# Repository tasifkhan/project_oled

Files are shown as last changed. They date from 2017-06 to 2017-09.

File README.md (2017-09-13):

## project_oled
- Display driver for 8x8 OLED array. Common anode setup for 64 devices, controlled by Darlington arrays and an Arduino Mega.
- Arduino code for displaying letters and numbers for the array, also a seven segment display.

### notes
- 2017_08_27 second round of cleaning. If you plan to use this design, DO NOT connect pin 10 of the Darlington arrays, leave that pin floating.
- 2017_07_18 cleanup. Hardware works with pin 10 NC. Uploading arduino firmware for seven segment and 4x4 displays.
- 2017_07_04 remove COM to GND connection in v1 (pin 10 NC). Other than that v1 works.

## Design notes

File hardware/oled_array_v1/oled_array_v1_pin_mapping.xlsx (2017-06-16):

 |  |  |  |  |  |  |  |  | x1 | x2
 |  |  |  |  |  |  |  |  | A7 | 13
 | 1 | 2 | 3 | 4 | 5 | 6 | 7 | 8 | A6 | 12
1 | A4 | A5 | A6 | A7 | 13 | 12 | 11 | 10 | A5 | 11
2 | A0 | A1 | A2 | A3 | 9 | 8 | 7 | 6 | A4 | 10
3 | A11 | A10 | A9 | A8 | 5 | 4 | 3 | 2 | A3 | 9
4 | 50 | 51 | 52 | 53 | 14 | 15 | 16 | 17 | A2 | 8
5 | 44 | 45 | 42 | 43 | 18 | 19 | 20 | 21 | A1 | 7
6 | 48 | 49 | 46 | 47 | 22 | 23 | 24 | 25 | A0 | 6
7 | 38 | 39 | 40 | 41 | 26 | 27 | 28 | 29 | A8 | 5
8 | 34 | 35 | 36 | 37 | 30 | 31 | 32 | 33 | A9 | 4
 |  |  |  |  |  |  |  |  | A10 | 3
 |  |  |  |  |  |  |  |  | A11 | 2
 |  |  |  |  |  |  |  |  | 53 | 14
 |  |  |  |  |  |  |  |  | 52 | 15
 |  |  |  |  |  |  |  |  | 51 | 16
 |  |  |  |  |  |  |  |  | 50 | 17
 |  |  |  |  |  |  |  |  | 43 | 18
 |  |  |  |  |  |  |  |  | 42 | 19
 |  |  |  |  |  |  |  |  | 45 | 20
 |  |  |  |  |  |  |  |  | 44 | 21
 |  |  |  |  |  |  |  |  | 47 | 22
 |  |  |  |  |  |  |  |  | 46 | 23
 |  |  |  |  |  |  |  |  | 49 | 24
 |  |  |  |  |  |  |  |  | 48 | 25
 |  |  |  |  |  |  |  |  | 41 | 26
 |  |  |  |  |  |  |  |  | 40 | 27
 |  |  |  |  |  |  |  |  | 39 | 28
 |  |  |  |  |  |  |  |  | 38 | 29
 |  |  |  |  |  |  |  |  | 37 | 30
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

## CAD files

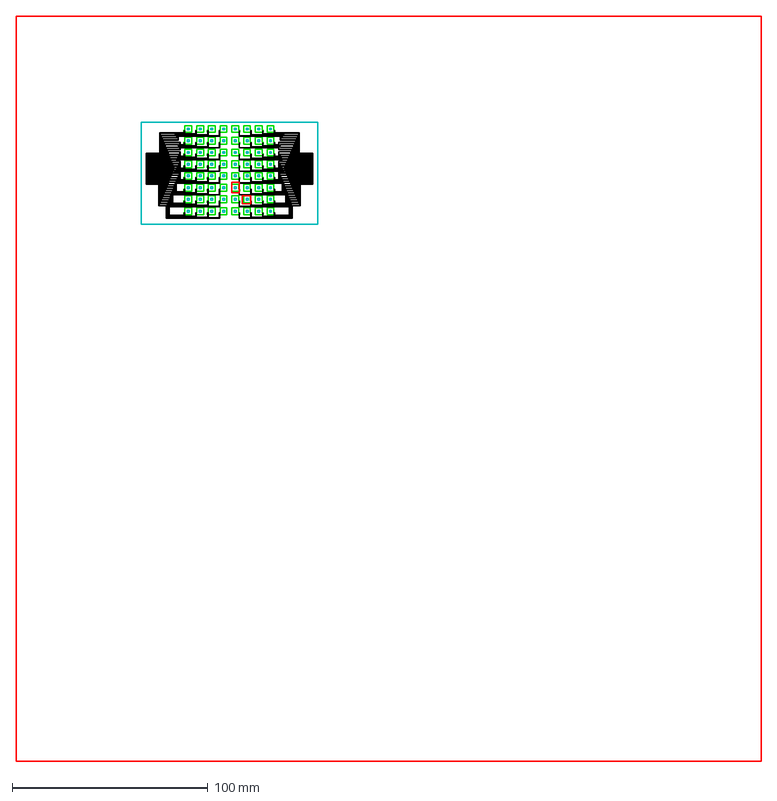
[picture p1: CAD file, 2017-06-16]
hardware/array_dxf/oled_array.dxf
381.0 x 381.0 mm

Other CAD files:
hardware/array_dxf/Master_OPD_array.dwg
hardware/array_dxf/oled_array.dwg

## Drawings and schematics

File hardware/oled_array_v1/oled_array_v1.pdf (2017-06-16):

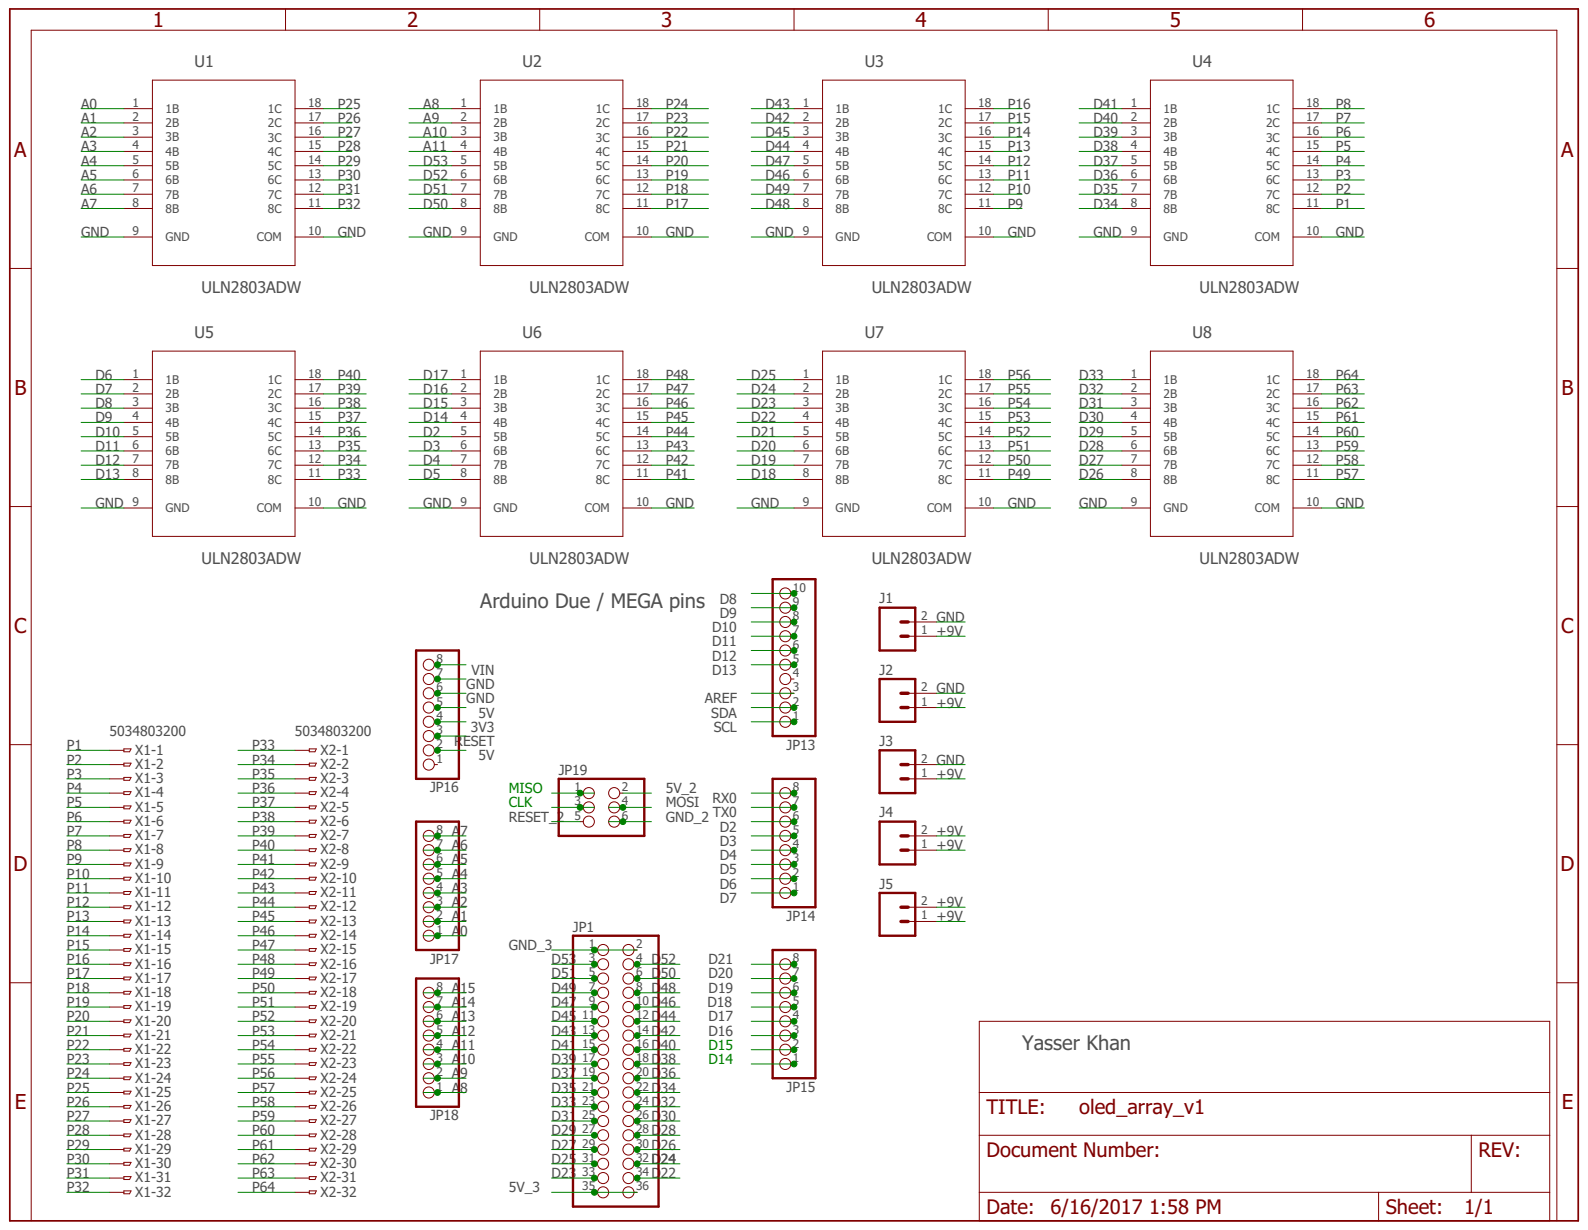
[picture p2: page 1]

Arduino Due / MEGA pins

Document Number: | REV:

Date: 6/16/2017 1:58 PM | Sheet: 1/1

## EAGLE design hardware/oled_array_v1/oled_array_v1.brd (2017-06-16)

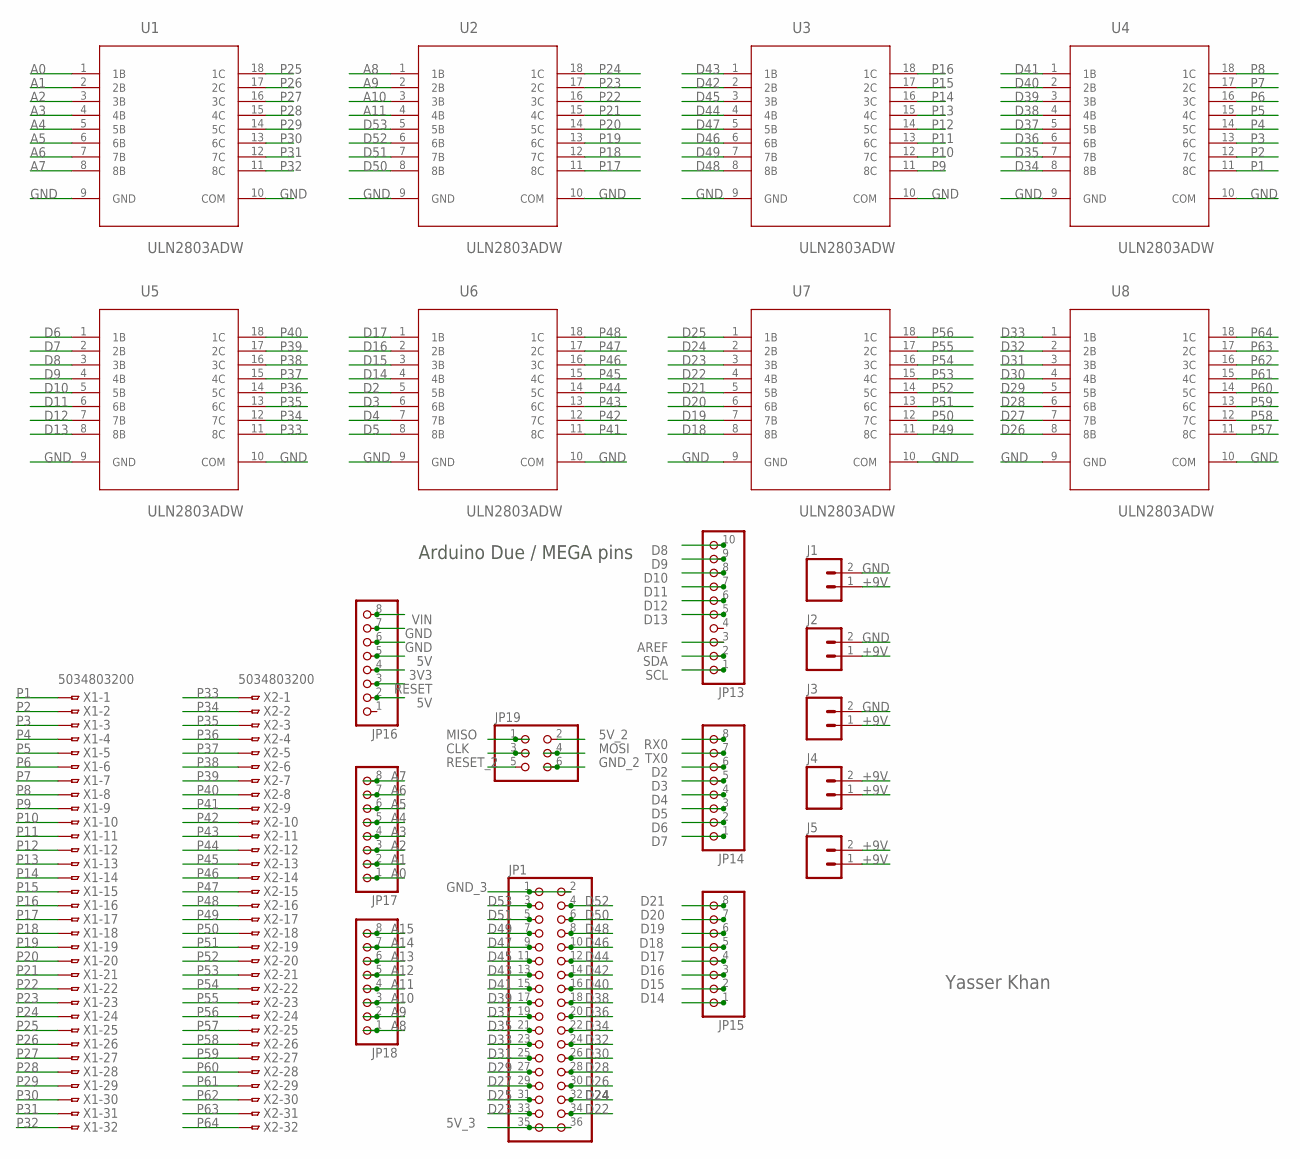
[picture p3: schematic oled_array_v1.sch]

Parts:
J1, J2, J3, J4, J5: M02PTH; 1X02
JP1: PINHD-2X18; 2X18
JP13: PINHD-1X10; 1X10
JP14, JP15, JP16, JP17, JP18: PINHD-1X8; 1X08
JP19: PINHD-2X3; 2X03
U1, U2, U3, U4, U5, U6, U7, U8: ULN2803ADW; SOIC127P1030X265-18N
X1, X2: 5034803200

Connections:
3V3: JP16.4
5V: JP16.2, JP16.5
5V_2: JP19.2
5V_3: JP1.35, JP1.36
+9V: J1.1, J2.1, J3.1, J4.1, J4.2, J5.1, J5.2
A0: JP17.1, U1.1 (1B)
A1: JP17.2, U1.2 (2B)
A2: JP17.3, U1.3 (3B)
A3: JP17.4, U1.4 (4B)
A4: JP17.5, U1.5 (5B)
A5: JP17.6, U1.6 (6B)
A6: JP17.7, U1.7 (7B)
A7: JP17.8, U1.8 (8B)
A8: JP18.1, U2.1 (1B)
A9: JP18.2, U2.2 (2B)
A10: JP18.3, U2.3 (3B)
A11: JP18.4, U2.4 (4B)
A12: JP18.5
A13: JP18.6
A14: JP18.7
A15: JP18.8
AREF: JP13.3
CLK: JP19.3
D2: JP14.6, U6.5 (5B)
D3: JP14.5, U6.6 (6B)
D4: JP14.4, U6.7 (7B)
D5: JP14.3, U6.8 (8B)
D6: JP14.2, U5.1 (1B)
D7: JP14.1, U5.2 (2B)
D8: JP13.10, U5.3 (3B)
D9: JP13.9, U5.4 (4B)
D10: JP13.8, U5.5 (5B)
D11: JP13.7, U5.6 (6B)
D12: JP13.6, U5.7 (7B)
D13: JP13.5, U5.8 (8B)
D14: JP15.1, U6.4 (4B)
D15: JP15.2, U6.3 (3B)
D16: JP15.3, U6.2 (2B)
D17: JP15.4, U6.1 (1B)
D18: JP15.5, U7.8 (8B)
D19: JP15.6, U7.7 (7B)
D20: JP15.7, U7.6 (6B)
D21: JP15.8, U7.5 (5B)
D22: JP1.34, U7.4 (4B)
D23: JP1.33, U7.3 (3B)
D24: JP1.32, U7.2 (2B)
D25: JP1.31, U7.1 (1B)
D26: JP1.30, U8.8 (8B)
D27: JP1.29, U8.7 (7B)
D28: JP1.28, U8.6 (6B)
D29: JP1.27, U8.5 (5B)
D30: JP1.26, U8.4 (4B)
D31: JP1.25, U8.3 (3B)
D32: JP1.24, U8.2 (2B)
D33: JP1.23, U8.1 (1B)
D34: JP1.22, U4.8 (8B)
D35: JP1.21, U4.7 (7B)
D36: JP1.20, U4.6 (6B)
D37: JP1.19, U4.5 (5B)
D38: JP1.18, U4.4 (4B)
D39: JP1.17, U4.3 (3B)
D40: JP1.16, U4.2 (2B)
D41: JP1.15, U4.1 (1B)
D42: JP1.14, U3.2 (2B)
D43: JP1.13, U3.1 (1B)
D44: JP1.12, U3.4 (4B)
D45: JP1.11, U3.3 (3B)
D46: JP1.10, U3.6 (6B)
D47: JP1.9, U3.5 (5B)
D48: JP1.8, U3.8 (8B)
D49: JP1.7, U3.7 (7B)
D50: JP1.6, U2.8 (8B)
D51: JP1.5, U2.7 (7B)
D52: JP1.4, U2.6 (6B)
D53: JP1.3, U2.5 (5B)
GND: J1.2, J2.2, J3.2, JP16.6, JP16.7, U1.9 (GND), U1.10 (COM), U2.9 (GND), U2.10 (COM), U3.9 (GND), U3.10 (COM), U4.9 (GND), U4.10 (COM), U5.9 (GND), U5.10 (COM), U6.9 (GND), U6.10 (COM), U7.9 (GND), U7.10 (COM), U8.9 (GND), U8.10 (COM)
GND_2: JP19.6
GND_3: JP1.1, JP1.2
MISO: JP19.1
MOSI: JP19.4
P1: U4.11 (8C), X1.1
P2: U4.12 (7C), X1.2
P3: U4.13 (6C), X1.3
P4: U4.14 (5C), X1.4
P5: U4.15 (4C), X1.5
P6: U4.16 (3C), X1.6
P7: U4.17 (2C), X1.7
P8: U4.18 (1C), X1.8
P9: U3.11 (8C), X1.9
P10: U3.12 (7C), X1.10
P11: U3.13 (6C), X1.11
P12: U3.14 (5C), X1.12
P13: U3.15 (4C), X1.13
P14: U3.16 (3C), X1.14
P15: U3.17 (2C), X1.15
P16: U3.18 (1C), X1.16
P17: U2.11 (8C), X1.17
P18: U2.12 (7C), X1.18
P19: U2.13 (6C), X1.19
P20: U2.14 (5C), X1.20
P21: U2.15 (4C), X1.21
P22: U2.16 (3C), X1.22
P23: U2.17 (2C), X1.23
P24: U2.18 (1C), X1.24
P25: U1.18 (1C), X1.25
P26: U1.17 (2C), X1.26
P27: U1.16 (3C), X1.27
P28: U1.15 (4C), X1.28
P29: U1.14 (5C), X1.29
P30: U1.13 (6C), X1.30
P31: U1.12 (7C), X1.31
P32: U1.11 (8C), X1.32
P33: U5.11 (8C), X2.1
P34: U5.12 (7C), X2.2
P35: U5.13 (6C), X2.3
P36: U5.14 (5C), X2.4
P37: U5.15 (4C), X2.5
P38: U5.16 (3C), X2.6
P39: U5.17 (2C), X2.7
P40: U5.18 (1C), X2.8
P41: U6.11 (8C), X2.9
P42: U6.12 (7C), X2.10
P43: U6.13 (6C), X2.11
P44: U6.14 (5C), X2.12
P45: U6.15 (4C), X2.13
P46: U6.16 (3C), X2.14
P47: U6.17 (2C), X2.15
P48: U6.18 (1C), X2.16
P49: U7.11 (8C), X2.17
P50: U7.12 (7C), X2.18
P51: U7.13 (6C), X2.19
P52: U7.14 (5C), X2.20
P53: U7.15 (4C), X2.21
P54: U7.16 (3C), X2.22
P55: U7.17 (2C), X2.23
P56: U7.18 (1C), X2.24
P57: U8.11 (8C), X2.25
P58: U8.12 (7C), X2.26
P59: U8.13 (6C), X2.27
P60: U8.14 (5C), X2.28
P61: U8.15 (4C), X2.29
P62: U8.16 (3C), X2.30
P63: U8.17 (2C), X2.31
P64: U8.18 (1C), X2.32
RESET: JP16.3
RESET_2: JP19.5
RX0: JP14.8
SCL: JP13.1
SDA: JP13.2
TX0: JP14.7
VIN: JP16.8

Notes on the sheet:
Arduino Due / MEGA pins
Yasser Khan

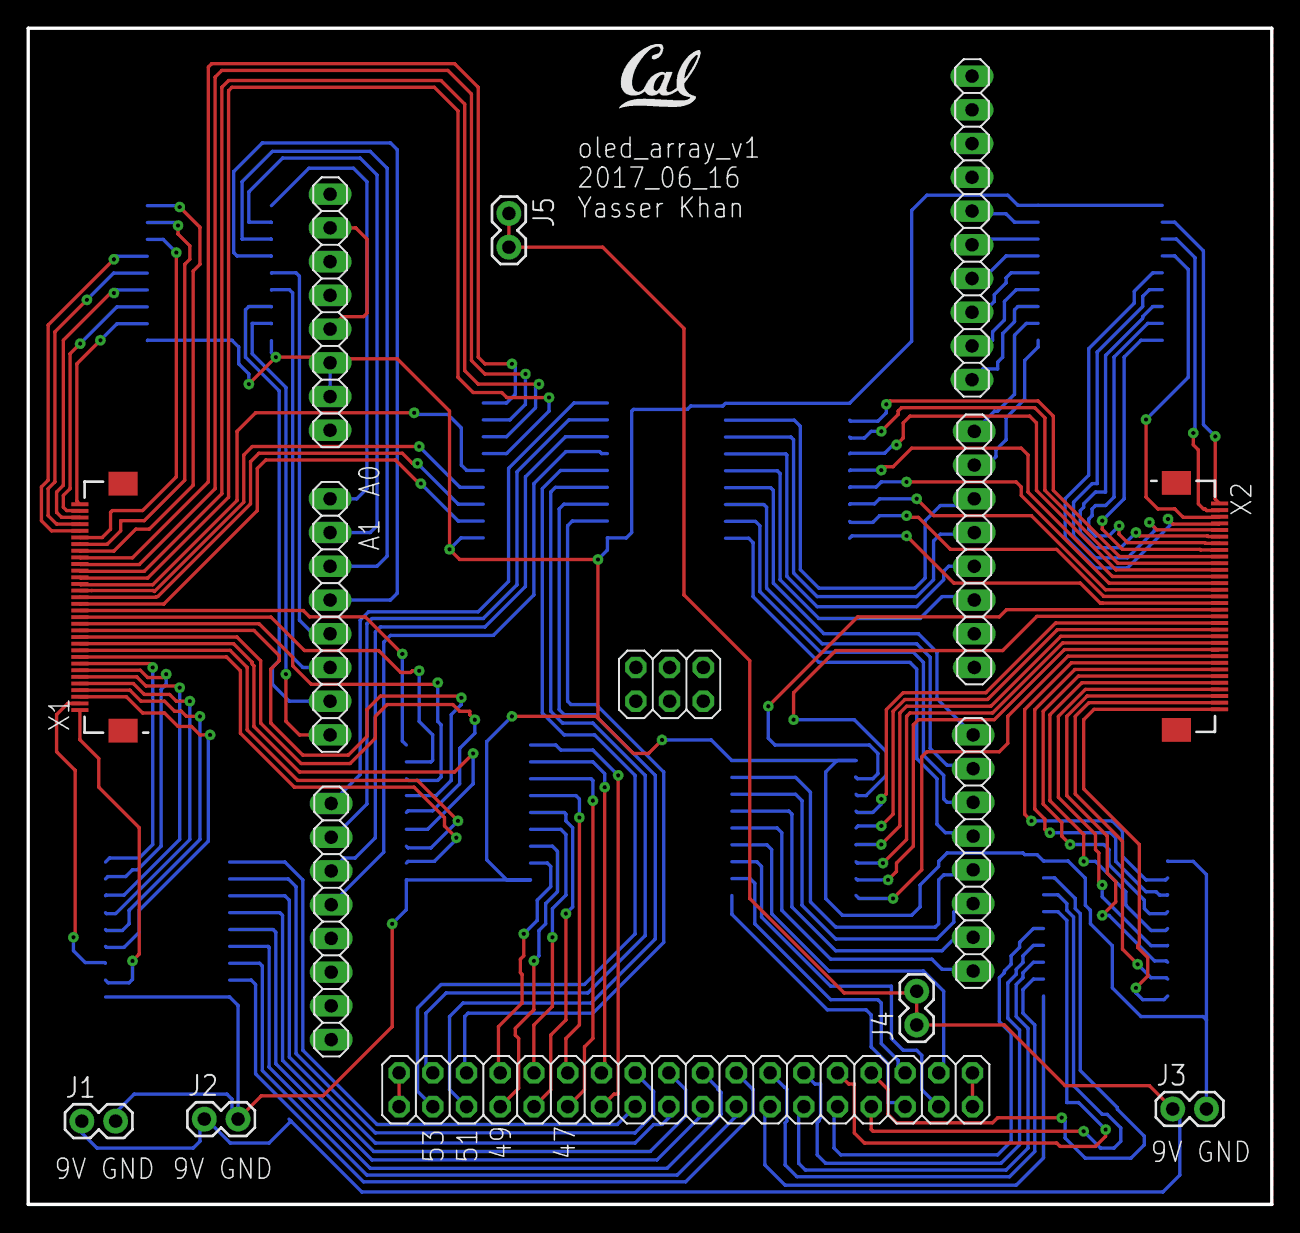
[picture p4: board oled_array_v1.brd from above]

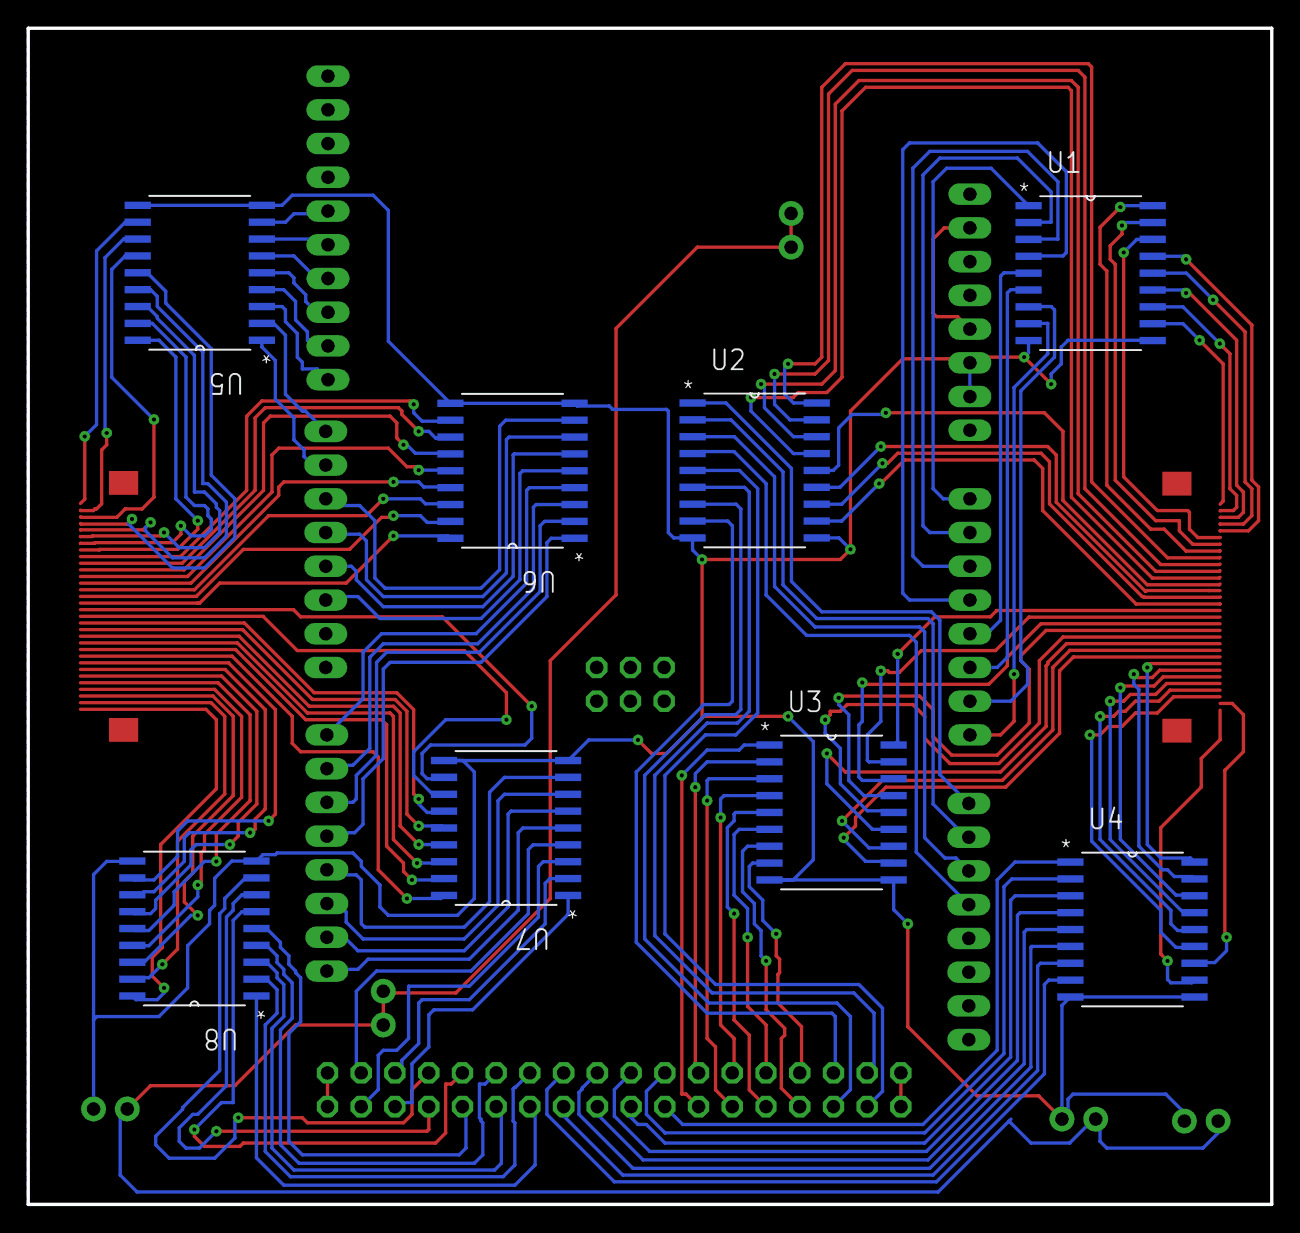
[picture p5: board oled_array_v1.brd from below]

Board: 2 copper layers, 93.6 x 88.6 mm, 23 parts (8 on the bottom side), 133 nets.

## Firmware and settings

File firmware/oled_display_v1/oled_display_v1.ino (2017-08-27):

/*
  displays CAL on a 4x4 display
*/

int controlPins[] = { // OLED lighting sequence
  0b1111111111111111, // all on
  0b1111100010001111, // C
  0b1111100111111001, // A
  0b1000100010001111, // L
};

int segmentPins[]= {33, 29, 25, 21, 32, 28, 24, 20, 31, 27, 23, 19, 30, 26, 22, 18}; // connection to the OLEDs

void setup() {
  // digital pins
  for (int i=2; i <= 55; i++){
      pinMode(i, OUTPUT);
  }

  pinMode(A0, OUTPUT);
  pinMode(A1, OUTPUT);
  pinMode(A2, OUTPUT);
  pinMode(A3, OUTPUT);
  pinMode(A4, OUTPUT);
  pinMode(A5, OUTPUT);
  pinMode(A6, OUTPUT);
  pinMode(A7, OUTPUT);
  pinMode(A8, OUTPUT);
  pinMode(A9, OUTPUT);
  pinMode(A10, OUTPUT);
  pinMode(A11, OUTPUT);
  pinMode(A12, OUTPUT);
  pinMode(A13, OUTPUT);
}


void loop() {
  // turning all off
  for (int i=2; i <= 55; i++){
    digitalWrite(i, LOW);
  }
  digitalWrite(A0, LOW);
  digitalWrite(A1, LOW);
  digitalWrite(A2, LOW);
  digitalWrite(A3, LOW);
  digitalWrite(A4, LOW);
  digitalWrite(A5, LOW);
  digitalWrite(A6, LOW);
  digitalWrite(A7, LOW);
  digitalWrite(A8, LOW);
  digitalWrite(A9, LOW);
  digitalWrite(A10, LOW);
  digitalWrite(A11, LOW);

  for (int j = 0; j < 4; j++){ // writing the four letters
    for (int i = 0; i < 16; i++){ // sequence for the 16 OLEDs
      digitalWrite(segmentPins[i], controlPins[j]>>(i) & 0b0000000000000001);
      Serial.print(controlPins[j]>>(i) & 0b0000000000000001);
    }
    delay(1000);
    Serial.print("\n");
  }
}

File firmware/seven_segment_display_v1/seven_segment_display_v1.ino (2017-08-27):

// counts up from 0 to 9 for digit 1, then does the same for digit 2

int controlPins[] = {
  // a b c d e f g a b c d e f g
  0b0011111111111111, // all on
  0b0000000000000000, // all off
  0b0000000000111111, // 0
  0b0000000000000110, // 1
  0b0000000001011011, // 2
  0b0000000001001111, // 3
  0b0000000001100110, // 4
  0b0000000001101101, // 5
  0b0000000001111101, // 6
  0b0000000000000111, // 7
  0b0000000001111111, // 8
  0b0000000001101111, // 9
  0b0001111111101111, // 09
  0b0000001101101111, // 19
  0b0010110111101111, // 29
  0b0010011111101111, // 39
  0b0011001101101111, // 49
  0b0011011011101111, // 59
  0b0011111011101111, // 69
  0b0000001111101111, // 79
  0b0011111111101111, // 89
  0b0011011111101111 // 99
};

int segmentPins[]= {12, 10, 6, 4, 2, 15, 8, 29, 17, 19, 21, 23, 27, 25};

void setup() {
  Serial.begin(9600);
  for (int i=2; i <= 55; i++){
      pinMode(i, OUTPUT);
   }
}

void loop() {
  for (int i=2; i <= 55; i++){
    digitalWrite(i, LOW);
  }

  // running OLED sequence

  for (int j = 0; j < 23; j++){ // 22 sequence changes
    for (int i = 0; i < 14; i++){ // 2 digit seven segments
      digitalWrite(segmentPins[i], controlPins[j]>>(i) & 0b0000000000000001);
      Serial.print(controlPins[j]>>(i) & 0b0000000000000001);
    }
    delay(500);
    Serial.print("\n");
  }
}

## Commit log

2017-06-16 Initial commit.
    [Master_OPD_array.dwg, oled_array.dwg, oled_array.dxf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]
2017-06-16 pinout added
    [oled_array_v1_pin_mapping.xlsx]

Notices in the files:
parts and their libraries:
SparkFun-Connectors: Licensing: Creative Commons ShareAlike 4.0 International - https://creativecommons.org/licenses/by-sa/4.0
